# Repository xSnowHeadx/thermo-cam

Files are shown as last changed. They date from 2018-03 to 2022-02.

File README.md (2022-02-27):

# thermo-cam

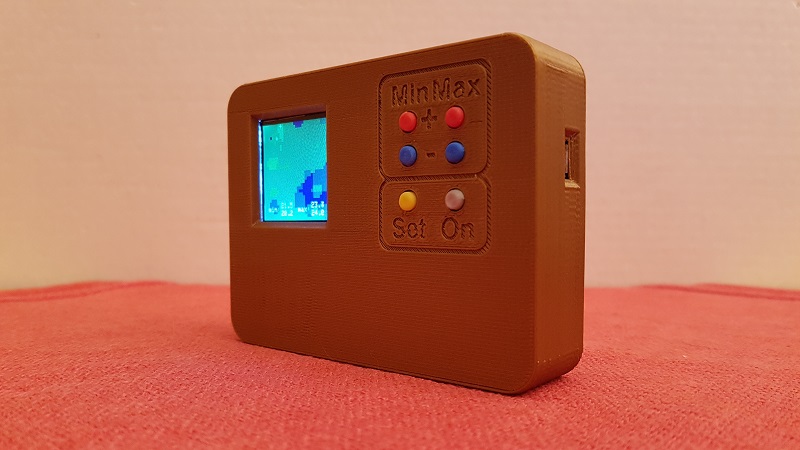
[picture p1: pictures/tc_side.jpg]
ThermoCam


Dieses Projekt enthält die Hard- und Softwarekomponenten für eine Eigenbau-Wärmebildkamera mit dem Sensor AMG8833 auf Basis einer ESP8266-12E NodeMCU mit Selbstkosten von etwa 80€.

----------

**Bitte beachten: dieses Projekt ist noch in Entwicklung. Es läuft zwar schon alles, aber an Verbesserungen und Erweiterungen von Hard- und Software wird noch 
gearbeitet.** 

----------

Basierend auf dem Beispiel [thermal\_cam\_interpolate](https://github.com/adafruit/Adafruit_AMG88xx/tree/master/examples/thermal_cam_interpolate "thermal_cam_interpolate") von [adafruit](https://www.adafruit.com/) wurde die Software für die ThermoCam entwickelt. Die Interpolationsfunktion "interpolation.cpp", welche die real 8x8 Bildpixel des Thermosensors auf 32x32 Pixel interpoliert wurde 1:1 von adafruit übernommen.

## Software 

Da der ESP8266 Arduino-kompatibel ist, kann die Software mit allen verfügbaren Arduino-Entwicklungsumgebungen gebaut und geflasht werden.
Dabei kommen folgende Standard-Arduino-Bibliotheken zum Einsatz:

- EEPROM
- SoftwareSerial
- SPI
- Wire

Folgende externe Bibliotheken müssen beschafft und entsprechend den Anleitungen der jeweiligen Entwicklungsumgebungen eingebunden werden:

- [Adafruit\_AMG_88xx\_Library](https://github.com/adafruit/Adafruit_AMG88xx) (Sensoransteuerung)
- [Adafruit\_ESP8266](https://github.com/adafruit/Adafruit_ESP8266) (Funktionen der NodeMCU)
- [Adafruit\_GFX\_Library](https://github.com/adafruit/Adafruit-GFX-Library) (Grafik- und Textausgabe)
- [ESP8266WiFi](https://github.com/esp8266/Arduino) (zum stromsparenden Abschalten des WiFi-Teils)
- [OneButton](https://github.com/mathertel/OneButton) (Tasterabfrage)
- [TFT_eSPI](https://github.com/Bodmer/TFT_eSPI) (schnellere LCD-Ansteuerung als von adafruit)
- [UrsAdc](http://bienonline.magix.net/public/esp8266-adc.html) (A/D-Wandlung für Spannungsmessung)

## Hardware 

Hier eine Liste der Hauptkomponenten mit Bezugsquellen

- Thermosensor-Breakout [AMG8833](https://www.adafruit.com/product/3538)
- TFT-Display-Breakout [ST7735R](https://www.adafruit.com/product/2088) 
- NodeMCU [ESP8266-12E](https://www.aliexpress.com/item/1pcs-NodeMCU-V3-Lua-WIFI-module-integration-of-ESP8266-extra-memory-32M-Flash-USB-serial-CH340G/32813713134.html)
- 3,7V-Akku [18650](https://www.aliexpress.com/item/2PCS-3-7V-4200mAh-18650-MICKTICK-Battery-lithium-Li-Ion-Rechargeable-Large-Capacity-Batteries-batteria-T6/32803586525.html)
- Akku-Lade- und Schutzschaltung [BMS](https://www.aliexpress.com/item/1S-3-7V-3A-li-ion-BMS-PCM-battery-protection-board-pcm-for-18650-lithium-ion/32673915806.html)
- Step-Up / Step-Down Spannungsregler [3V3](https://www.aliexpress.com/item/mini-2-in-1-DC-DC-Step-Down-Step-Up-Converter-1-8V-5V-to-3/32764847210.html) 
- 6 Stück Kurzhubtaster [9308](https://www.reichelt.com/fr/en/Switches-Tactile/TASTER-9308/3/index.html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)
- Gehäuse und Tasterköpfe [ThermoCam](https://www.prusaprinters.org/prints/140136-thermocam) (müssen selbst gedruckt oder in Auftrag gegeben werden)

Neben einem Stück Lochrasterplatte für die Taster, Kabeln, Widerständen und Kontaktblechstreifen sind noch einige Flachkopf-Schrauben M3x5 und M2,5x5 erforderlich. Ich habe die Löcher von Display und Sensor auf 3mm aufgebohrt und generell M3-Schrauben verwendet. 

Da Schiebeschalter unpraktisch sind und um bei Nichtbenutzung das Gerät über die Software abschalten zu können, erfolgt das Schalten der Stromversorgung elektronisch. Die im Schaltplan angegebenen Mosfet-Transistoren sind nur als Beispiel zu sehen. Alle Transistoren mit einem Maximalstrom von 500mA und einer Tresholdspannung kleiner 2V sind verwendbar. 

Da die auf den Boards verwendeten 3,3V-Linearregler eine Spannungsdifferenz von mindestens 0,4V - 0,5V zwischen Ein- und Ausgang benötigen, versagen sie bereits bei der Akku-Nennspannung von 3,7V. Deshalb sorgt der Step-Up / Step-Down-Wandler dafür, daß die Module in einem Bereich der Eingangsspannung von 3,3V bis 5V (beim Laden über USB) konstant mit 3,3V versorgt werden.

Das BMS dient dem Schutz des Akkus gegen Unter- und Überladung und wird (versehen mit Kontaktblechstreifen für den Akku) 

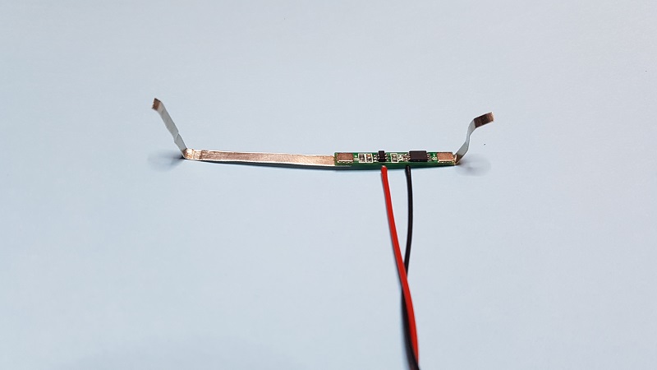
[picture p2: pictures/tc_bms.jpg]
BMS


in dem Kanal unter diesem platziert. In das Verbindungskabel vom Akku zur Schaltung sollte eine lösbare Kupplung eingefügt werden, um den Akku von der Schaltung trennen zu können. 

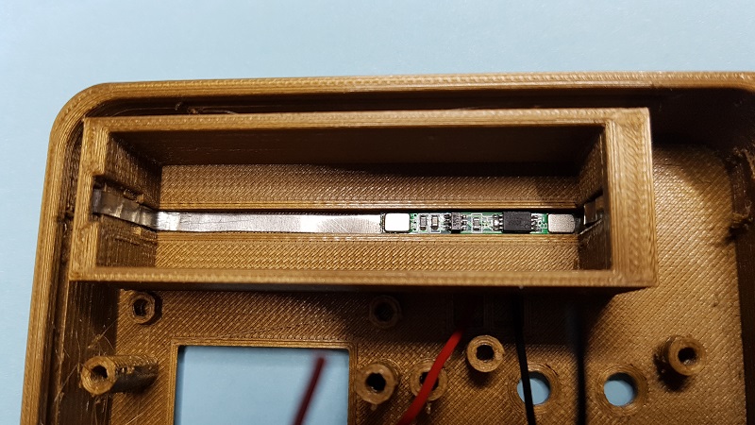
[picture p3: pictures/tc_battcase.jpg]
BMS unter Akku


Das Innenleben sieht letztendlich so aus:

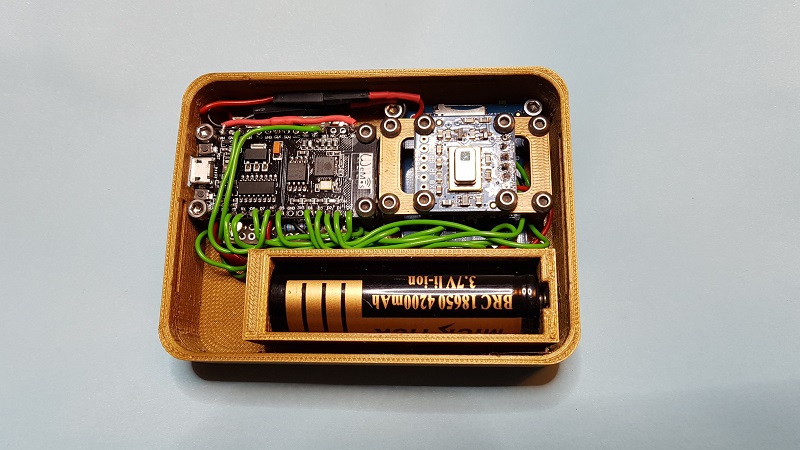
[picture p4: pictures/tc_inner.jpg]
Innenleben


## Bedienung

Nach dem Einschalten über den Taster **On** läuft die Kamera im Interpolationsmodus mit automatischer Farbskala-Anpassung. Auf der unteren linken Seite des Displays wird neben "min:" oben die kleinste Temperatur innerhalb des Bildes angezeigt. Darunter in einer Art Schleppzeigerfunktion die kleinste seit dem Start oder Update gemessene Temperatur. Diese wird als Referenz für die Farbe Blau verwendet. Analog werden rechts neben "max:" die jeweiligen Maximalwerte mit der Referenz für Rot angezeigt. Somit paßt die Kamera die Farbskala automatisch an den aktuellen Temperaturbereich an. An der Stelle der höchsten Temperatur im Bild wir ein weißes **+** Zeichen eingeblendet.
Hat man allerdings kurzzeitig einen sehr heißen Punkt im Bild gehabt, erreichen ab dann die niedrigeren Temperaturen nicht mehr den Rot-Pegel, was zu einer blau/grün-lastigen Bilddarstellung führt. In diesem Fall kann durch kurzes Drücken der Taste **Set** die Schleppzeigerfunktion auf die aktuellen Bildwerte zurückgesetzt werden. Das Bild zeigt nun wieder das volle Farbspektrum.  

Mit einem längeren Druck auf die **Set**-Taste kann man den Automatik-Modus ausschalten. Die Schleppzeiger-Werte werden nun in Grau dargestellt und können mit den Tasten **Min+**, **Min-**, **Max+** und **Max-** manuell eingestellt werden. Dabei ist keine kleinere Differenz zwischen Min und Max als 5 grd einstellbar, um die Anzeige sinnvoll zu halten.

Ein zweiter längerer Druck auf **Set** schaltet die Interpolation aus. Das hat zwar keinen praktischen Wert, aber es ist interessant zu sehen, wie das Original-Sensorsignal ohne Interpolation aussieht. Mit einem dritten langen Druck auf **Set** wird wieder in den anfänglichen Automatikmodus zurückgeschaltet. 

Ausgeschaltet wird die Kamera durch einen Doppelklick auf **Set**. Im Batteriebetrieb schaltet sich die Kamera nach 5 Minuten ohne Tastenbetätigung automatisch aus, um den Akku zu schonen. Wird die Kamera über ein USB-Kabel versorgt, ist die automatische Abschaltung deaktiviert.  

Die Akkuspannung wird ständig überwacht. Unterhalb von 3,5V erscheint in der rechten oberen Display-Ecke ein gelbes Batteriesymbol als Warnung. Dieses wechselt unterhalb einer Spannung von 3,35V auf Rot und beginnt zu blinken. Sinkt die Spannung unter 3,3V schaltet sich die Kamera automatisch ab.  
 
Ein Doppelklick auf **Min+** zeigt die aktuelle Eingangsspannung der Schaltung, in der Regel also die Akkuspannung, an. Damit kann man die noch verbleibende Laufzeit abschätzen.  Bei einer Stromaufnahme der Kamera von ca. 120mA reicht ein voll geladener Akku für mindestens 30 Stunden. Ein erneuter Doppelklick auf **Min+** wechselt zur Standardanzeige zurück. Damit sowohl diese Anzeige als auch die Spannungsüberwachung mit genauen Werten arbeiten, empfiehlt sich die Kalibrierung der Spannungsmessung. Dazu wechselt man mit einem Doppelklick auf **Min-** in den Kalibriermodus. Dabei wird die Spannung angezeigt, die der Prozessor meint gemessen zu haben. Die tatsächliche Spannung ist nun am Vin-Pin des ESP8266 mit einem genauen Voltmeter zu messen und mit dem gemessenen Wert die Anzeige zu korrigieren. Die jeweils blinkende Stelle kann dabei mit den Tasten **Max+** und **Max-** angepaßt werden, die Tasten **Min+** und **Min-** wechseln die Position der blinkenden Stelle. Für größere Änderungen können die Tasten **Max+** und **Max-** nach dem Drücken auch gedrückt gehalten werden. Die Werte beginnen dann schnell durchzulaufen.  
Soll die Eingabe gespeichert werden, ist die **Set**-Taste lange gedrückt zu halten. Die Kamera wechselt nach dem Speichern wieder in den normalen Anzeigemodus. Soll der Kalibriermodus ohne Speichern des Wertes verlassen werden, geschieht das über einen erneuten Doppelklick auf **Min-**.

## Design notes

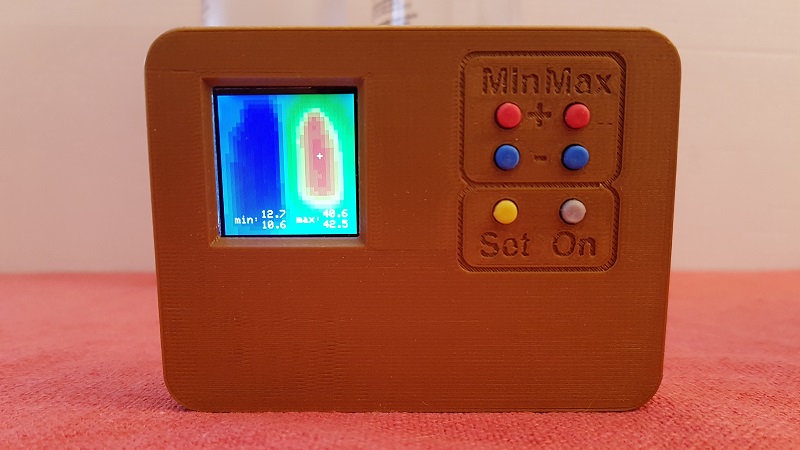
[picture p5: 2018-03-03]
pictures/tc_back.jpg

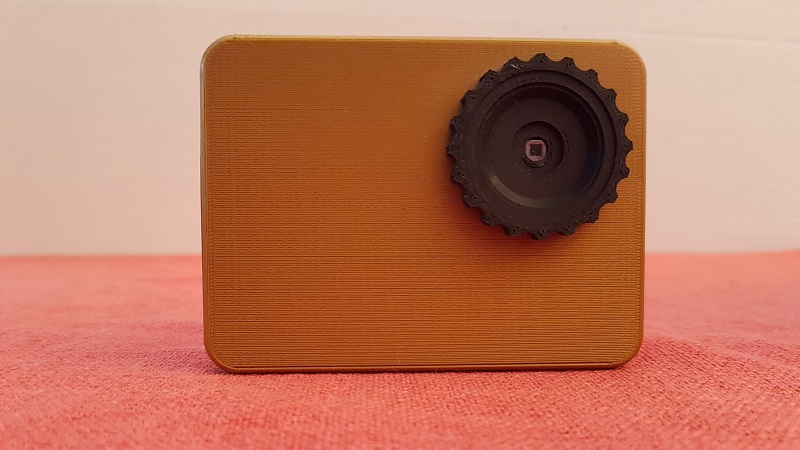
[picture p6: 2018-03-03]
pictures/tc_front.jpg

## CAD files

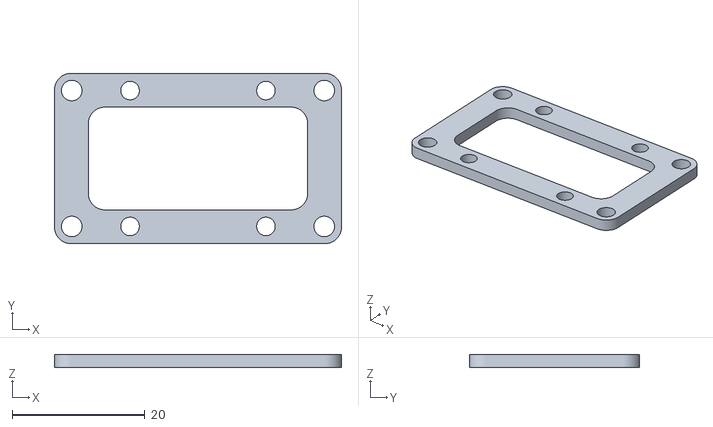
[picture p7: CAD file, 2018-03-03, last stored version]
mechanics/AMG_PLate.stl
43.3 x 25.7 x 2.00

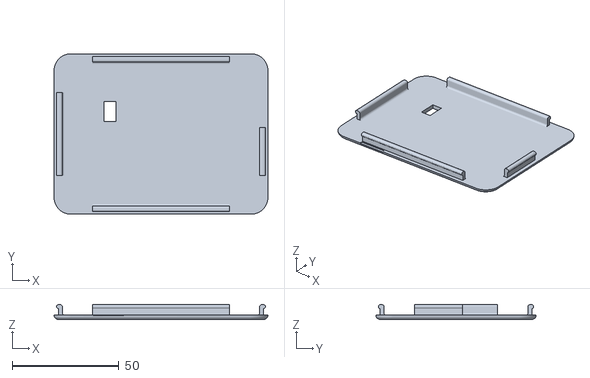
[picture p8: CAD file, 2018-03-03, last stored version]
mechanics/TC_Front.stl
100.0 x 75.0 x 6.90

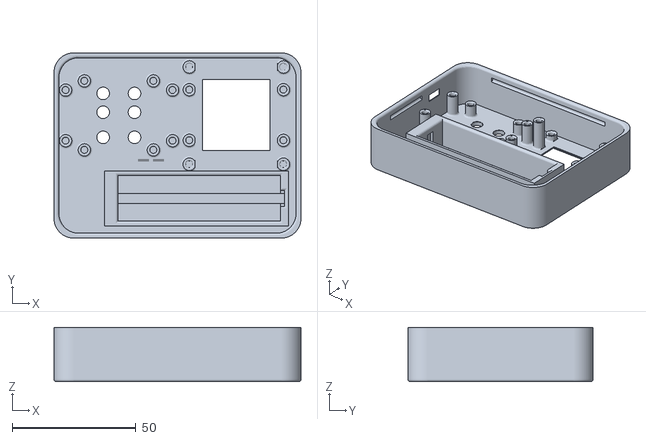
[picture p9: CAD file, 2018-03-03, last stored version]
mechanics/TC_Back.stl
100.0 x 75.0 x 22.0

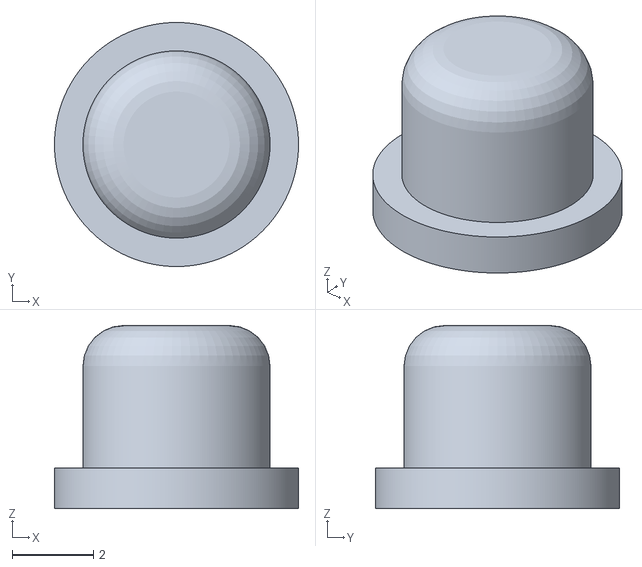
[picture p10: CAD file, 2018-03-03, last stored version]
mechanics/TC_Button.stl
6.00 x 6.00 x 4.50

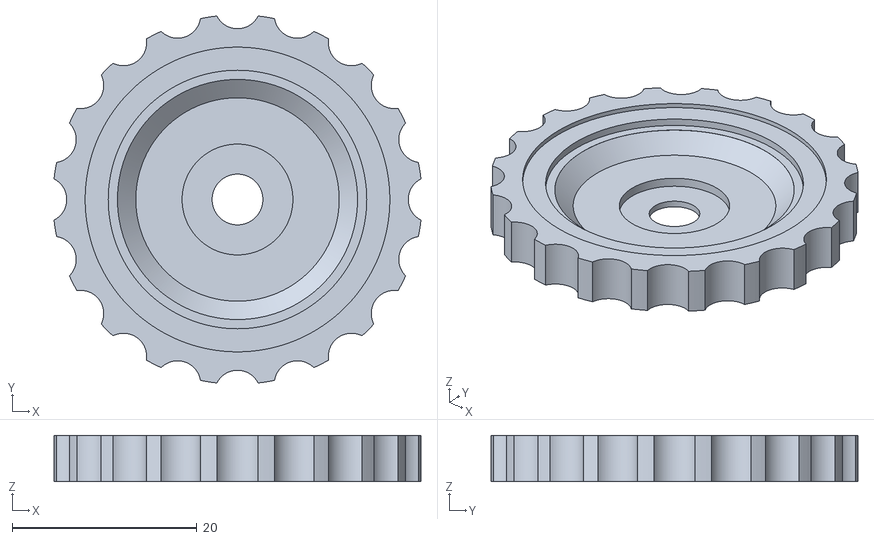
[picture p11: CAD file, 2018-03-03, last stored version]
mechanics/TC_Deko.stl
39.8 x 39.8 x 5.00

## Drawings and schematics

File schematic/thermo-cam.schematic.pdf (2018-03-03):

A

A

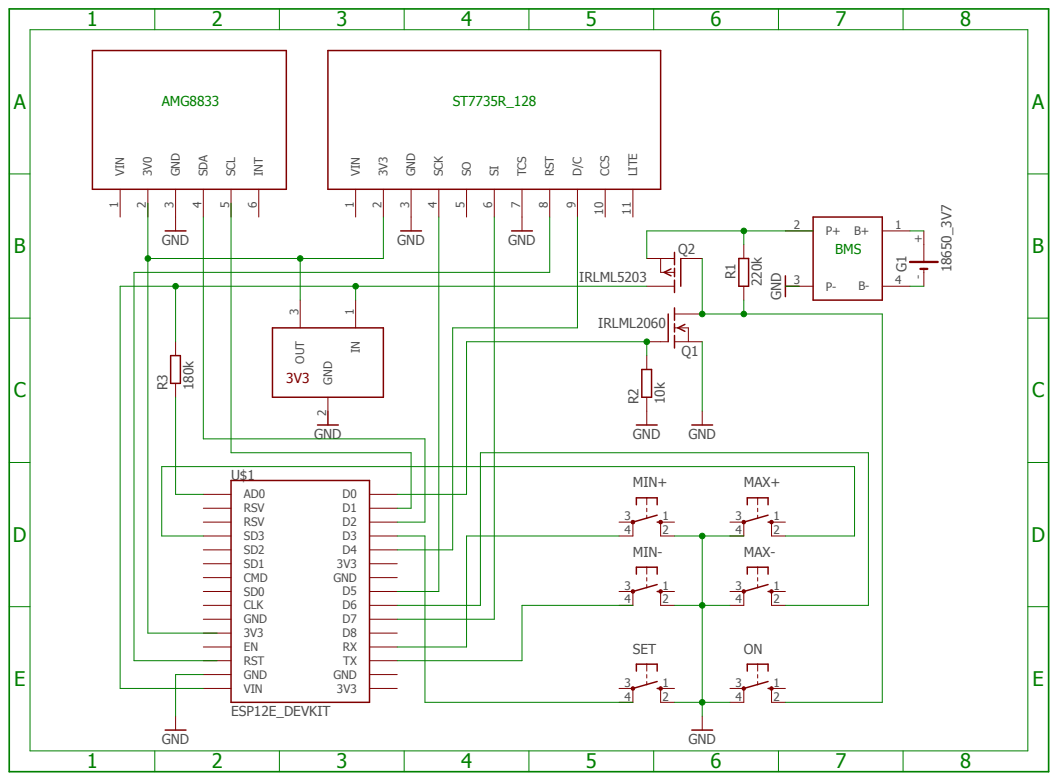
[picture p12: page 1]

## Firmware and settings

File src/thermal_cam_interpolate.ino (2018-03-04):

/***************************************************************************
 Firmware for a ThermoCam

 Based on an example from Dean Miller, James DeVito & ladyada for Adafruit
 Industries.
 ***************************************************************************/

// ------------------begin ESP8266'centric----------------------------------
#define FREQUENCY     80                  // valid 80, 160

//
#include "ESP8266WiFi.h"
extern "C" {
#include "user_interface.h"
}
// ------------------end ESP8266'centric------------------------------------

#include <Adafruit_GFX.h>
#include <TFT_eSPI.h>
#include <SPI.h>
#include <Wire.h>
#include <Adafruit_AMG88xx.h>
#include <eeprom.h>
#include "OneButton.h"
#include "UrsADC.h"

#define EEPROM_SIZE 128
enum {
  EEP_VALID,
  EEP_CALV,
  EEP_NEXT = EEP_CALV + sizeof(double),
};

// define the button-pins
#define B_MODE  		0
#define B_MAXP 			10
#define B_MAXM 			12
#define B_MINP  		3
#define B_MINM  		1
#define O_PWR  			16

// define position and size of the battery symbol
#define BATT_X 21
#define BATT_Y  9
#define BATT_START_X	100
#define BATT_START_Y	5

// define voltage limit levels
#define VBATT_CRIT		3.5
#define VBATT_EMPT		3.35
#define VBATT_OFF		3.3

// a helper macro
#define min(a,b) ((a)<(b)?(a):(b))

//low range of the sensor (this will be blue on the screen)
int MINTEMP = 15;

//high range of the sensor (this will be red on the screen)
int MAXTEMP = 35;

// the yellow battery symbol
const unsigned short bat_critical[] = {
0xFE41, 0xFE41, 0xFE41, 0xFE41, 0xFE41, 0xFE41, 0xFE41, 0xFE41, 0xFE41, 0xFE41, 0xFE41, 0xFE41, 0xFE41, 0xFE41, 0xFE41, 0xFE41,   // 0x0010 (16) pixels
0xFE41, 0xFE41, 0xFE41, 0xFFFF, 0xFFFF, 0xFE41, 0xFE41, 0xFE41, 0xFE41, 0xFE41, 0xFE41, 0xFE41, 0xFE41, 0xFE41, 0xFE41, 0xFE41,   // 0x0020 (32) pixels
0xFE41, 0xFE41, 0xFE41, 0xFE41, 0xFE41, 0xFE41, 0xFE41, 0xFE41, 0xFE41, 0xFFFF, 0xFE41, 0xFE41, 0xFFFF, 0xFFFF, 0xFFFF, 0xFFFF,   // 0x0030 (48) pixels
0xFFFF, 0xFFFF, 0xFFFF, 0xFFFF, 0xFFFF, 0xFFFF, 0xFFFF, 0xFFFF, 0xFFFF, 0xFFFF, 0xFFFF, 0xFFFF, 0xFE41, 0xFE41, 0xFFFF, 0xFE41,   // 0x0040 (64) pixels
0xFE41, 0xFFFF, 0xFE41, 0xFE41, 0xFFFF, 0xFFFF, 0xFFFF, 0xFFFF, 0xFFFF, 0xFFFF, 0xFFFF, 0xFFFF, 0xFFFF, 0xFFFF, 0xFFFF, 0xFFFF,   // 0x0050 (80) pixels
0xFFFF, 0xFE41, 0xFE41, 0xFE41, 0xFE41, 0xFE41, 0xFFFF, 0xFE41, 0xFE41, 0xFFFF, 0xFFFF, 0xFFFF, 0xFFFF, 0xFFFF, 0xFFFF, 0xFFFF,   // 0x0060 (96) pixels
0xFFFF, 0xFFFF, 0xFFFF, 0xFFFF, 0xFFFF, 0xFFFF, 0xFE41, 0xFE41, 0xFE41, 0xFE41, 0xFE41, 0xFFFF, 0xFE41, 0xFE41, 0xFFFF, 0xFFFF,   // 0x0070 (112) pixels
0xFFFF, 0xFFFF, 0xFFFF, 0xFFFF, 0xFFFF, 0xFFFF, 0xFFFF, 0xFFFF, 0xFFFF, 0xFFFF, 0xFFFF, 0xFE41, 0xFE41, 0xFE41, 0xFE41, 0xFE41,   // 0x0080 (128) pixels
0xFFFF, 0xFFFF, 0xFFFF, 0xFFFF, 0xFFFF, 0xFFFF, 0xFFFF, 0xFFFF, 0xFFFF, 0xFFFF, 0xFFFF, 0xFFFF, 0xFFFF, 0xFFFF, 0xFFFF, 0xFFFF,   // 0x0090 (144) pixels
0xFE41, 0xFE41, 0xFFFF, 0xFE41, 0xFE41, 0xFE41, 0xFE41, 0xFE41, 0xFE41, 0xFE41, 0xFE41, 0xFE41, 0xFE41, 0xFE41, 0xFE41, 0xFE41,   // 0x00A0 (160) pixels
0xFE41, 0xFE41, 0xFE41, 0xFE41, 0xFE41, 0xFE41, 0xFE41, 0xFFFF, 0xFFFF, 0xFE41, 0xFE41, 0xFE41, 0xFE41, 0xFE41, 0xFE41, 0xFE41,
0xFE41, 0xFE41, 0xFE41, 0xFE41, 0xFE41, 0xFE41, 0xFE41, 0xFE41, 0xFE41, 0xFE41, 0xFE41, 0xFFFF, 0xFFFF, 0xFFFF,
};

// the red battery symbol
const unsigned short bat_empty[] = {
0xE8E4, 0xE8E4, 0xE8E4, 0xE8E4, 0xE8E4, 0xE8E4, 0xE8E4, 0xE8E4, 0xE8E4, 0xE8E4, 0xE8E4, 0xE8E4, 0xE8E4, 0xE8E4, 0xE8E4, 0xE8E4,   // 0x0010 (16) pixels
0xE8E4, 0xE8E4, 0xE8E4, 0xFFFF, 0xFFFF, 0xE8E4, 0xE8E4, 0xE8E4, 0xE8E4, 0xE8E4, 0xE8E4, 0xE8E4, 0xE8E4, 0xE8E4, 0xE8E4, 0xE8E4,   // 0x0020 (32) pixels
0xE8E4, 0xE8E4, 0xE8E4, 0xE8E4, 0xE8E4, 0xE8E4, 0xE8E4, 0xE8E4, 0xE8E4, 0xFFFF, 0xE8E4, 0xE8E4, 0xFFFF, 0xFFFF, 0xFFFF, 0xFFFF,   // 0x0030 (48) pixels
0xFFFF, 0xFFFF, 0xFFFF, 0xFFFF, 0xFFFF, 0xFFFF, 0xFFFF, 0xFFFF, 0xFFFF, 0xFFFF, 0xFFFF, 0xFFFF, 0xE8E4, 0xE8E4, 0xFFFF, 0xE8E4,   // 0x0040 (64) pixels
0xE8E4, 0xFFFF, 0xFFFF, 0xFFFF, 0xFFFF, 0xFFFF, 0xFFFF, 0xFFFF, 0xFFFF, 0xFFFF, 0xFFFF, 0xFFFF, 0xFFFF, 0xFFFF, 0xFFFF, 0xFFFF,   // 0x0050 (80) pixels
0xFFFF, 0xE8E4, 0xE8E4, 0xE8E4, 0xE8E4, 0xE8E4, 0xFFFF, 0xFFFF, 0xFFFF, 0xFFFF, 0xFFFF, 0xFFFF, 0xFFFF, 0xFFFF, 0xFFFF, 0xFFFF,   // 0x0060 (96) pixels
0xFFFF, 0xFFFF, 0xFFFF, 0xFFFF, 0xFFFF, 0xFFFF, 0xE8E4, 0xE8E4, 0xE8E4, 0xE8E4, 0xE8E4, 0xFFFF, 0xFFFF, 0xFFFF, 0xFFFF, 0xFFFF,   // 0x0070 (112) pixels
0xFFFF, 0xFFFF, 0xFFFF, 0xFFFF, 0xFFFF, 0xFFFF, 0xFFFF, 0xFFFF, 0xFFFF, 0xFFFF, 0xFFFF, 0xE8E4, 0xE8E4, 0xE8E4, 0xE8E4, 0xE8E4,   // 0x0080 (128) pixels
0xFFFF, 0xFFFF, 0xFFFF, 0xFFFF, 0xFFFF, 0xFFFF, 0xFFFF, 0xFFFF, 0xFFFF, 0xFFFF, 0xFFFF, 0xFFFF, 0xFFFF, 0xFFFF, 0xFFFF, 0xFFFF,   // 0x0090 (144) pixels
0xE8E4, 0xE8E4, 0xFFFF, 0xE8E4, 0xE8E4, 0xE8E4, 0xE8E4, 0xE8E4, 0xE8E4, 0xE8E4, 0xE8E4, 0xE8E4, 0xE8E4, 0xE8E4, 0xE8E4, 0xE8E4,   // 0x00A0 (160) pixels
0xE8E4, 0xE8E4, 0xE8E4, 0xE8E4, 0xE8E4, 0xE8E4, 0xE8E4, 0xFFFF, 0xE8E4, 0xE8E4, 0xE8E4, 0xE8E4, 0xE8E4, 0xE8E4, 0xE8E4, 0xE8E4,
0xE8E4, 0xE8E4, 0xE8E4, 0xE8E4, 0xE8E4, 0xE8E4, 0xE8E4, 0xE8E4, 0xE8E4, 0xE8E4, 0xE8E4, 0xFFFF, 0xFFFF, 0xFFFF,
};

//the colormap for temperatures
const uint16_t camColors[] = {0x480F,
0x400F,0x400F,0x400F,0x4010,0x3810,0x3810,0x3810,0x3810,0x3010,0x3010,
0x3010,0x2810,0x2810,0x2810,0x2810,0x2010,0x2010,0x2010,0x1810,0x1810,
0x1811,0x1811,0x1011,0x1011,0x1011,0x0811,0x0811,0x0811,0x0011,0x0011,
0x0011,0x0011,0x0011,0x0031,0x0031,0x0051,0x0072,0x0072,0x0092,0x00B2,
0x00B2,0x00D2,0x00F2,0x00F2,0x0112,0x0132,0x0152,0x0152,0x0172,0x0192,
0x0192,0x01B2,0x01D2,0x01F3,0x01F3,0x0213,0x0233,0x0253,0x0253,0x0273,
0x0293,0x02B3,0x02D3,0x02D3,0x02F3,0x0313,0x0333,0x0333,0x0353,0x0373,
0x0394,0x03B4,0x03D4,0x03D4,0x03F4,0x0414,0x0434,0x0454,0x0474,0x0474,
0x0494,0x04B4,0x04D4,0x04F4,0x0514,0x0534,0x0534,0x0554,0x0554,0x0574,
0x0574,0x0573,0x0573,0x0573,0x0572,0x0572,0x0572,0x0571,0x0591,0x0591,
0x0590,0x0590,0x058F,0x058F,0x058F,0x058E,0x05AE,0x05AE,0x05AD,0x05AD,
0x05AD,0x05AC,0x05AC,0x05AB,0x05CB,0x05CB,0x05CA,0x05CA,0x05CA,0x05C9,
0x05C9,0x05C8,0x05E8,0x05E8,0x05E7,0x05E7,0x05E6,0x05E6,0x05E6,0x05E5,
0x05E5,0x0604,0x0604,0x0604,0x0603,0x0603,0x0602,0x0602,0x0601,0x0621,
0x0621,0x0620,0x0620,0x0620,0x0620,0x0E20,0x0E20,0x0E40,0x1640,0x1640,
0x1E40,0x1E40,0x2640,0x2640,0x2E40,0x2E60,0x3660,0x3660,0x3E60,0x3E60,
0x3E60,0x4660,0x4660,0x4E60,0x4E80,0x5680,0x5680,0x5E80,0x5E80,0x6680,
0x6680,0x6E80,0x6EA0,0x76A0,0x76A0,0x7EA0,0x7EA0,0x86A0,0x86A0,0x8EA0,
0x8EC0,0x96C0,0x96C0,0x9EC0,0x9EC0,0xA6C0,0xAEC0,0xAEC0,0xB6E0,0xB6E0,
0xBEE0,0xBEE0,0xC6E0,0xC6E0,0xCEE0,0xCEE0,0xD6E0,0xD700,0xDF00,0xDEE0,
0xDEC0,0xDEA0,0xDE80,0xDE80,0xE660,0xE640,0xE620,0xE600,0xE5E0,0xE5C0,
0xE5A0,0xE580,0xE560,0xE540,0xE520,0xE500,0xE4E0,0xE4C0,0xE4A0,0xE480,
0xE460,0xEC40,0xEC20,0xEC00,0xEBE0,0xEBC0,0xEBA0,0xEB80,0xEB60,0xEB40,
0xEB20,0xEB00,0xEAE0,0xEAC0,0xEAA0,0xEA80,0xEA60,0xEA40,0xF220,0xF200,
0xF1E0,0xF1C0,0xF1A0,0xF180,0xF160,0xF140,0xF100,0xF0E0,0xF0C0,0xF0A0,
0xF080,0xF060,0xF040,0xF020,0xF800};


#define AUTO_OFF_TIMEOUT	300000L		// shut down after 5 minutes without action
#define AMG_COLS 			8			// 8 columns of thermo pixel
#define AMG_ROWS 			8			// 8 rows of thermo pixel
#define INTERPOLATED_COLS 	32			// 32 temperature points per column on TFT
#define INTERPOLATED_ROWS 	32			// 32 temperature points per row on TFT
#define RAWMODE				0x02		// bitmask for not interpolated display
#define MANUAL				0x01		// bitmask for manual temperature ranges

bool blink_flag = 			false;		// common flag for blink functions
bool volt_flag = 			false;		// voltage display mode active
bool cal_flag = 			false;		// calibration mode active
double cal_val, cal_step;				// help values for calibration mode
int cal_pos;
double  VBATT_CORR = 		0.0051939453125;	// scaling factor for voltage measurement
double min_drag = 			999.0;		// lower value of trailing pointers
double max_drag = 		   -999.0;		// higher value of trailing pointers
uint32_t blink_millis = 	0;			// timer for blink functions
uint32_t auto_off_millis;				// timer for automatic shutdown
float pixels[AMG_COLS * AMG_ROWS];
float dest_2d[INTERPOLATED_ROWS * INTERPOLATED_COLS];
volatile int modeflag = 	0;
volatile int draginit = 	1;

TFT_eSPI tft = TFT_eSPI();       		// Invoke custom library
Adafruit_AMG88xx amg;					// create sensor object
OneButton b_mode(B_MODE, true);			// create button objects
OneButton b_maxp(B_MAXP, true);
OneButton b_maxm(B_MAXM , true);
OneButton b_minp(B_MINP, true);
OneButton b_minm(B_MINM, true);

// calculate the coordinates of given point index
float get_point(float *p, uint8_t rows, uint8_t cols, int8_t x, int8_t y);

// interpolate the 8x8 sensor array to 32x32 for TFT
void interpolate_image(float *src, uint8_t src_rows, uint8_t src_cols, float *dest, uint8_t dest_rows, uint8_t dest_cols);

// draw the pixels regarding the measured temperatures
void drawpixels(float *p, uint8_t rows, uint8_t cols, uint8_t boxWidth, uint8_t boxHeight);

// read a double value from given address in EEPROM
double eep_read_double(int address)
{
	unsigned int i;
	double dval;
	unsigned char *cp = (unsigned char*)&dval;

	for(i = 0; i < sizeof(double); i++)
	{
		*cp = EEPROM.read(address + i);
		++cp;
	}
	return dval;
}

// write a double value to given address in EEPROM
void eep_write_double(int address, double value)
{
	unsigned int i;
	double dval = value;
	unsigned char *cp = (unsigned char*)&dval;

	for(i = 0; i < sizeof(double); i++)
	{
		EEPROM.write(address + i, *cp);
		++cp;
	}
	EEPROM.commit();
}

// measure the battery voltage
double read_batt(void)
{
	return ((double)UrsAdc.read() * VBATT_CORR);
}

// doubleclick function of MIN-
void toggle_cal_flag(void)
{
	if(cal_flag ^= 1)
	{
		volt_flag = 0;
		cal_val = read_batt();
		cal_step = 1.0;
		cal_pos = 0;
		tft.setTextSize(2);
		tft.fillScreen(TFT_BLACK);
		tft.setCursor(12, tft.height() / 2 - 49 );
		tft.print("measured");
		tft.setCursor(12, tft.height() / 2 - 32 );
		tft.print("Voltage:");
	}
}

// doubleclick function of MIN+
void toggle_volt_flag(void)
{
	if(!cal_flag)
	{
		if(volt_flag ^= 1)
		{
			tft.setTextSize(2);
			tft.setCursor(12, tft.height() / 2 - 32 );
			tft.fillScreen(TFT_BLACK);
			tft.print("Voltage:");
		}
		auto_off_millis = millis();
	}
}

// click function of SET
void init_dragging(void)
{
	draginit = 1;
	auto_off_millis = millis();
}

// longpress function of SET
void next_mode(void)
{
	if(cal_flag)
	{
		VBATT_CORR = cal_val / (double)UrsAdc.read();
		eep_write_double(EEP_CALV, VBATT_CORR);
		cal_flag = 0;
	}
	else
	{
		++modeflag;
		modeflag %= 3;
		if (modeflag & MANUAL)
		{
			max_drag = (int)max_drag;
			min_drag = (int)min_drag;
		}
	}
	auto_off_millis = millis();
}

// click function of MAX+
void do_maxp(void)
{
	if(cal_flag)
	{
		if((cal_val + cal_step) <= 5.5)
			cal_val += cal_step;
		blink_millis = 0;
	}
	else
	{
		if (modeflag & MANUAL)
			++max_drag;
	}
	auto_off_millis = millis();
}

// click function of MAX-
void do_maxm(void)
{
	if(cal_flag)
	{
		if((cal_val - cal_step) >= 3.0)
			cal_val -= cal_step;
		blink_millis = 0;
	}
	else
	{
		if (modeflag & MANUAL)
			if((max_drag - min_drag) > 6)
				--max_drag;
	}
	auto_off_millis = millis();
}

// click function of MIN+
void do_minp(void)
{
	if(cal_flag)
	{
		if(cal_pos < 3)
		{
			cal_pos++;
			cal_step /= 10.0;
		}
		blink_millis = 0;
	}
	else
	{
		if (modeflag & MANUAL)
			if((max_drag - min_drag) > 6)
				++min_drag;
	}
	auto_off_millis = millis();
}

// click function of MIN-
void do_minm(void)
{
	if(cal_flag)
	{
		if(cal_pos > 0)
		{
			cal_pos--;
			cal_step *= 10.0;
		}
		blink_millis = 0;
	}
	else
	{
		if (modeflag & MANUAL)
			--min_drag;
	}
	auto_off_millis = millis();
}

// doubleclick function of SET and common shutdown
void power_off(void)
{
	digitalWrite(O_PWR, LOW);
}

// show the battery symbol if necessary
void show_batt(void)
{
	int i, j;
	unsigned short *bptr;
	uint32_t last_millis = millis();
	static double voltage;

	voltage = read_batt();
	if((last_millis - blink_millis) > 1000)
	{
		blink_flag ^= 1;
		blink_millis = last_millis;
	}
	if(voltage < VBATT_CRIT)
	{
		bptr = (unsigned short*)bat_critical;
		if(voltage < VBATT_EMPT)
			bptr = (unsigned short*)bat_empty;
		if(voltage < VBATT_OFF)
			power_off();
		if(blink_flag)
		{
			for(j = 0; j < BATT_Y; j++)
			{
				for(i = 0; i < BATT_X; i++)
				{
					if(*bptr != TFT_WHITE)
						tft.drawPixel(BATT_START_X + i, BATT_START_Y + j, (unsigned short)*bptr);
					++bptr;
				}
			}
		}
	}
}

// initial settings
void setup()
{
	WiFi.forceSleepBegin();                  // turn off ESP8266 RF
	delay(1);                                // give RF section time to shutdown
	system_update_cpu_freq(FREQUENCY);

	pinMode(O_PWR, OUTPUT);
	digitalWrite(O_PWR, HIGH);				// hold the power switch

	Serial.begin(115200);
	Serial.println("\n\nAMG88xx Interpolated Thermal Camera!");

	EEPROM.begin(EEPROM_SIZE);
	if (EEPROM.read(EEP_VALID) == 0xAA)
	{
		VBATT_CORR = eep_read_double(EEP_CALV);
	}
	else
	{
		EEPROM.write(EEP_VALID, 0xAA);
		eep_write_double(EEP_CALV, VBATT_CORR);
	}

	// attach the button functions
	b_mode.attachClick(init_dragging);
	b_mode.attachLongPressStart(next_mode);
	b_mode.attachDoubleClick(power_off);
	b_maxp.attachClick(do_maxp);
	b_maxp.attachDuringLongPress(do_maxp);
	b_maxm.attachClick(do_maxm);
	b_maxm.attachDuringLongPress(do_maxm);
	b_minp.attachClick(do_minp);
	b_minp.attachDuringLongPress(do_minp);
	b_minp.attachDoubleClick(toggle_volt_flag);
	b_minm.attachClick(do_minm);
	b_minm.attachDuringLongPress(do_minm);
	b_minm.attachDoubleClick(toggle_cal_flag);

	// init the TFT
	tft.begin();
	tft.setRotation(2);
	tft.fillScreen(TFT_BLACK);

	auto_off_millis = millis();

	// init the sensor
	if (!amg.begin())
	{
		Serial.println("Could not find a valid AMG88xx sensor, check wiring!");
		while (1)
		{
			delay(1);
		}
	}
	Serial.println("-- Thermal Camera Test --");
	Serial.end();		// no further serial output

	// reconfigure the button pins (serial output is disabled now)
	pinMode(B_MAXM, INPUT_PULLUP);
	pinMode(B_MAXP, INPUT_PULLUP);
	pinMode(B_MINM, INPUT_PULLUP);
	pinMode(B_MINP, INPUT_PULLUP);
	pinMode(B_MODE, INPUT_PULLUP);

	wdt_reset();
}

// the cyclic loop function
void loop()
{
	int i, j;
	float tval;
	volatile unsigned long amill;
	char txt[64];

	// read the sensor values
	amg.readPixels(pixels);

	// flip the array because of headfirst mounted sensor
	j = AMG_COLS * AMG_ROWS - 1;
	for(i=0; i < (AMG_COLS * AMG_ROWS / 2); i++)
	{
		tval = pixels[j];
		pixels[j] = pixels[i];
		pixels[i] = tval;
		--j;
	}

	// do the button functions
	b_mode.tick();
	b_maxp.tick();
	b_maxm.tick();
	b_minp.tick();
	b_minm.tick();

	amill = millis();

	if(cal_flag)								// calibration mode?
	{
		if((amill - blink_millis) > 500)
		{
			dtostrf(cal_val, 5, 3, txt);		// print calibration value
			if(blink_flag)
			{
				txt[cal_pos + ((cal_pos)?1:0)] = ' ';	// let active position blink
			}
			tft.setCursor(30, tft.height() / 2 - 5);
			tft.fillRect(30, tft.height() / 2 - 5, 60, 20, TFT_BLACK);
			tft.print(txt);						// write text to TFT
			blink_millis = amill;
			blink_flag ^= 1;
		}
	}
	else if(volt_flag)							// voltage display mode?
	{
		if((amill - blink_millis) > 500)
		{
			tft.setCursor(30, tft.height() / 2 - 5);
			dtostrf(read_batt(), 4, 2, txt);	// print voltage value
			strcat(txt, " V");
			tft.fillRect(30, tft.height() / 2 - 5, 46, 20, TFT_BLACK);
			tft.print(txt);						// write text to TFT
			blink_millis = amill;
			blink_flag ^= 1;
		}
	}
	else										// normal display mode
	{
		if (modeflag & RAWMODE)					// interpolation disabled?
		{
			unsigned char boxsize = min(tft.width() / AMG_COLS, tft.height() / AMG_ROWS);
			// draw pixels not interpolated
			drawpixels(pixels, AMG_ROWS, AMG_COLS, boxsize, boxsize);
		}
		else									// interpolation enabled?
		{
			unsigned char boxsize = min((uint8_t)(tft.width() / INTERPOLATED_COLS),
					(uint8_t)(tft.height() / INTERPOLATED_COLS));

			// draw interpolated pixels
			interpolate_image(pixels, AMG_ROWS, AMG_COLS, dest_2d, INTERPOLATED_ROWS, INTERPOLATED_COLS);
			drawpixels(dest_2d, INTERPOLATED_ROWS, INTERPOLATED_COLS, boxsize, boxsize);
		}
	}
	// test for necessary auto shutdown
	if((amill - auto_off_millis) > AUTO_OFF_TIMEOUT)
		if(read_batt() < 4.1)
			power_off();

	wdt_reset();
}

void drawpixels(float *p, uint8_t rows, uint8_t cols, uint8_t boxWidth, uint8_t boxHeight)
{
	int colorTemp;
	uint8_t colorIndex;
	unsigned long lmill = 0;
	double tmin = 100.0, tmax = 0;
	char txt[64];
	unsigned char xmax = 0, ymax = 0, tpos;

	// for all pixels
	for (int y = 0; y < rows; y++)
	{
		for (int x = 0; x < cols; x++)
		{
			// find minimal and maximal values
			float val = get_point(p, rows, cols, x, y);
			if (val >= MAXTEMP)
				colorTemp = MAXTEMP;
			else if (val <= MINTEMP)
				colorTemp = MINTEMP;
			else
				colorTemp = val;
			if (val > tmax)
			{
				tmax = val;
				xmax = x;
				ymax = y;
			}
			if ((val < tmin) && (val > 1.0))
				tmin = val;

			if (draginit)
			{
				draginit = 0;
				if (modeflag & MANUAL)
				{
					max_drag = (int)max_drag;
					min_drag = (int)min_drag;
				}
				else
				{
					min_drag = tmin;
					max_drag = tmax;
				}
			}
			else
			{
				if (!(modeflag & MANUAL))
				{
					if ((tmin > 0.0) && (tmin < min_drag))
						min_drag = tmin;
					if (tmax > max_drag)
						max_drag = tmax;
				}
			}
			// map temperature to color
			colorIndex = map(colorTemp, MINTEMP, MAXTEMP, 0, 255);
			colorIndex = constrain(colorIndex, 0, 255);
			// draw the colored rectangle
			tft.fillRect(boxWidth * x, boxHeight * y, boxWidth, boxHeight, camColors[colorIndex]);
		}
		// show battery symbol if necessary
		show_batt();
	}
	// refresh text every 750ms
	if ((millis() - lmill) > 750)
	{
		tpos = 105;
		lmill = millis();
		tft.setTextColor(TFT_WHITE);
		tft.setTextSize(1);
		strcpy(txt, "min:      max:");
		tft.setCursor(10, tpos + 5);
		tft.print(txt);
		dtostrf(tmin, 4, 1, txt);
		tft.setCursor(36, tpos);
		tft.print(txt);
		dtostrf(tmax, 4, 1, txt);
		tft.setCursor(96, tpos);
		tft.print(txt);
		if (modeflag & MANUAL)
			tft.setTextColor(TFT_LIGHTGREY);
		tpos += 10;
		dtostrf(min_drag, 4, 1, txt);
		tft.setCursor(36, tpos);
		tft.print(txt);
		dtostrf(max_drag, 4, 1, txt);
		tft.setCursor(96, tpos);
		tft.print(txt);
		tpos = boxWidth * xmax + (boxWidth >> 1) - 2;
		if(tpos > tft.width() - 2 * boxWidth)
			tpos = tft.width() - 2 * boxWidth;
		tft.setCursor(tpos , boxHeight * ymax + (boxHeight >> 1) - 2);
		tft.print("+");
		MINTEMP = min_drag;
		MAXTEMP = max_drag;
		if((MAXTEMP - MINTEMP) < 5)
		{
			MAXTEMP = MINTEMP + 5;
		}
	}
}
